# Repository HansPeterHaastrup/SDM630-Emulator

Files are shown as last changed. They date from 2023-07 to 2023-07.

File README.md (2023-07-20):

# SDM630-Emulator
Emulate the basic functionality of the Eastron SDM630 using Home-Assistant, MQTT and Arduino

## About
I have a large house. I wanted to install solar cells on my roof. I already have the Eastron SDM630 metering my connection and I am happy to get that information in to my Home-assistant installation.
The Deye inverters support the Eastron meter but by connecting the meter directly would not only require me to pull an absurdly long cable through my house but I would also loose the monitoring ability in Home-assistant.
This project emulates the SDM630 so the home-assistant data can be retained while allowing the inverters to get fast updates on the current power consumption.

## Prerequisites
1. A Home-assistant installation.
2. A MQTT Broker (Mosquitto is usually installed along Home-assistant)
3. ESPHome (installable on Home-assistant)
4. and SDM630 meter (Duh)

## Hardware
The hardware required is the same on each end - An ESP8266 with RS-485 interface. I have opted to use a cheap interface found on ebay and a NodeMCU. I have made a little enclosure for it. Powering the sensor in each end is done by a small USB power supply. nothing fancy.

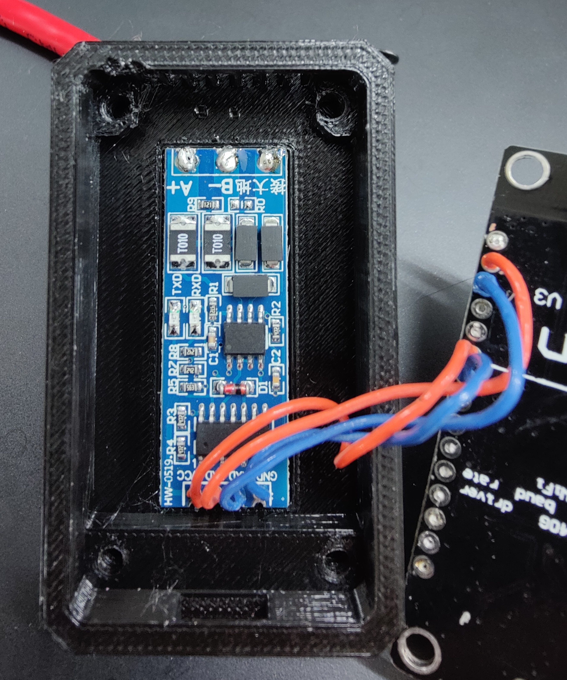
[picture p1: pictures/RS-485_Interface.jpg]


The enclosure have 3 small holes for screw terminals, from left to right the connections are GND,B,A.
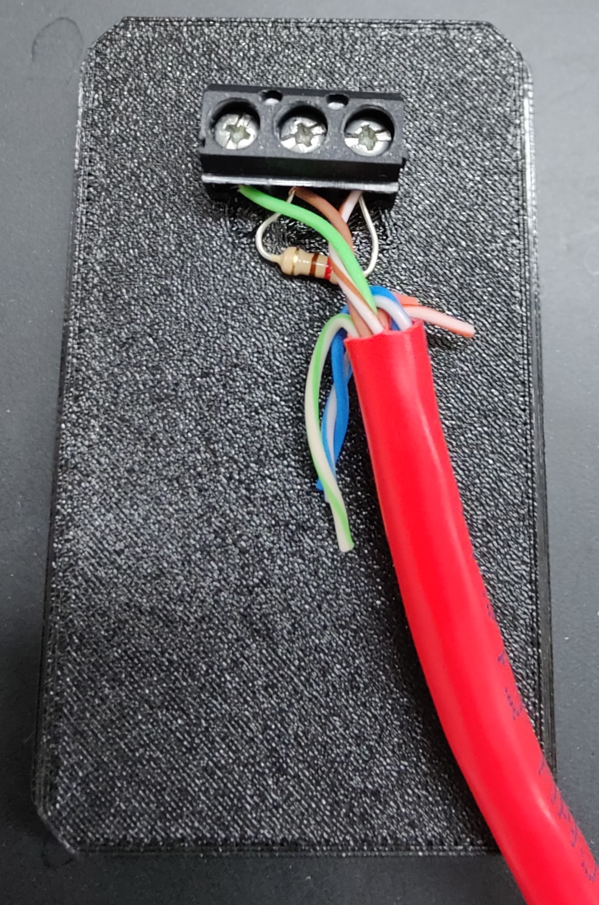
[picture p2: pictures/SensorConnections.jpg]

I have added the 120Ohm resistor but I'm not completely sure it's needed (nor the GND wire but hey, it works!)

## Firmware for metering node
For the sensor in the metering end I have used ESPHome. Create a standard sensor and add the following:
```
mqtt:
  broker: IP-TO-THE-BROKER (IP of Home-assistant)
  username: !secret mosquittouser
  password: !secret mosquittopassword

substitutions:
  phase_A: R
  phase_B: S
  phase_C: T

uart:
  rx_pin: 5
  tx_pin: 4
  baud_rate: 9600
  stop_bits: 1

sensor:
  - platform: sdm_meter
    phase_a:
      current:
        name: $phase_A Current
      voltage:
        name: $phase_A Voltage
      active_power:
        name: $phase_A Power
      power_factor:
        name: $phase_A Power Factor
      apparent_power:
        name: $phase_A Apparent Power
      reactive_power:
        name: $phase_A Reactive Power
      phase_angle:
        name: $phase_A Phase Angle
    phase_b:
      current:
        name: $phase_B Current
      voltage:
        name: $phase_B Voltage
      active_power:
        name: $phase_B Power
      power_factor:
        name: $phase_B Power Factor
      apparent_power:
        name: $phase_B Apparent Power
      reactive_power:
        name: $phase_B Reactive Power
      phase_angle:
        name: $phase_B Phase Angle
    phase_c:
      current:
        name: $phase_C Current
      voltage:
        name: $phase_C Voltage
      active_power:
        name: $phase_C Power
      power_factor:
        name: $phase_C Power Factor
      apparent_power:
        name: $phase_C Apparent Power
      reactive_power:
        name: $phase_C Reactive Power
      phase_angle:
        name: $phase_C Phase Angle

    frequency:
      name: "Frequency"
    total_power:
      name: "Total Power"
    import_active_energy:
      name: "Import Active Energy"
    export_active_energy:
      name: "Export Active Energy"
    import_reactive_energy:
      name: "Import Reactive Energy"
    export_reactive_energy:
      name: "Export Reactive Energy"
    
    update_interval: 2s
```
This will make all the data available in Home-assistant.
A few highlights:
1. The MQTT section. by adding this section you will get ALL values sent to the MQTT broker as well. it IS possible to script just the few registers needed for the emulator to work but this is by far the easiest solution.
2. The UART section. On the nodeMCU pin 4 and 5 works fine. YMMW
3. Last line. Update interval. The inverter queries the meter every second. While it is possible to get the sensor to answer faster by requesting less information I rather like the datapoints here. So far the 2 seconds seem to work just great.
4. The names of the phases. I have chosen the R,S,T naming convention (Root-Stem-Top) but you cah choose whichever you want. You just have to update the names in the receiving end as well if you do.

## Firmware for inverter node
See the Arduino sketch supplied in the repo.
You will need the MQTT libary 'PubSubClient' by Nick O'Leary installed to compile this project.
Adjust the section in 'User definitions' accordingly.

## Getting it all to work
There are many steps to get this thing to work. I recommend first installing the metering node and getting data flowing into the Home-Assistant. This should be fairly straight forward if you have used ESPHome before.
When the node ide running you will have to look at the MQTT part. For this I have found the program [MQTT Explorer](http://mqtt-explorer.com/) extremely helpful. by using this and connecting to your MQTT Broker you can see the data available on different topics. I am by no means an expert on MQTT but I could easily see what was going on.
Next, it's time to set up the receiving node. Please bear in mind that this project as of now is made for Deye inverters. Your inverter might ask for different registers that I haven't relayed through this method. YMMW.
Using the debug prints in the arduino sketch can prove extremely helpful. Start with making the sensor see the updates on your sensor topic in the MQTT broker. When that is running properly you can add the RS-485 communication with the inverter.
Good luck :)

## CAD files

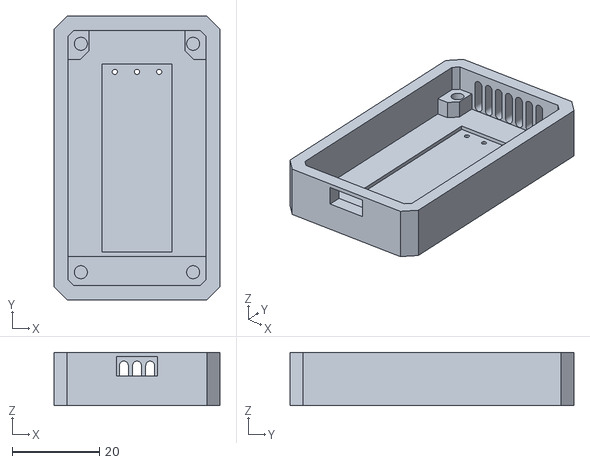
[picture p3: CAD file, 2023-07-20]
Mechanical/RS-485Node_Front.stl
38.0 x 65.0 x 12.2

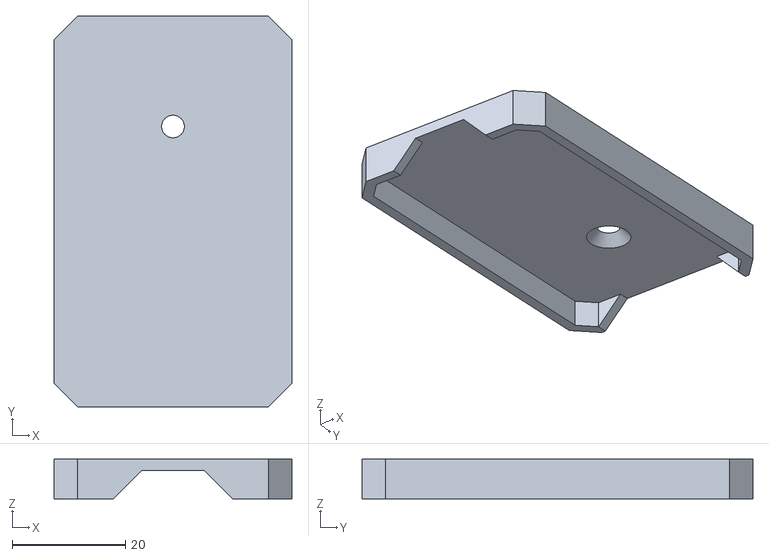
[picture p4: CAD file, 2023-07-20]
Mechanical/RS-485Node_Back.stl
42.0 x 69.0 x 7.00

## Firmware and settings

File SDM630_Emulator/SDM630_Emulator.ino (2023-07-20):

//#include <WiFi.h> //if using ESP32
#include <ESP8266WiFi.h>  //is using ESP8266
#include <PubSubClient.h>
#include <Wire.h>
#include <SoftwareSerial.h>

SoftwareSerial SoftSerial(4, 5);
WiFiClient espClient;
PubSubClient client(espClient);

/******************USER DEFINITIONS***************************/
#define DEBUG 0                                       //Set to 1 if you want debug prints :)
#define DEBUG_RS485 1

const char* ssid = "SSID";                    //WiFi SSID/Password combination
const char* password = "PASSWORD";

// Add your MQTT Broker IP address:
const char* mqtt_server = "IP-OF-YOUR-BROKER";
const char* mtqq_user = "MQTT-USERNAME";
const char* mtqq_password = "MQTT-PASSWORD";
const char* mtqq_device = "SDM630Emulator";
const char* mtqq_topic = "powersensor/sensor/#";        //the sensor to subscribe to (the # enables all sub-topics)
/******************END USER DEFINITIONS***********************/

uint8_t registers[160]; //this will hold the data up to and inclusive parameter 40 as per SDM630 manual. (4-bytes per parameter)

uint16_t calc_crc(uint8_t* data, uint8_t length) {
  uint16_t crc = 0xFFFF;
  for (int pos = 0; pos < length; pos++) {
    crc ^= data[pos];
    for (int i = 0; i < 8; i++) {
      if ((crc & 1) != 0) {
        crc >>= 1;
        crc ^= 0xA001;
      } else {
        crc >>= 1;
      }
    }
  }
  return crc;
}

void handleInverter() 
{
  if (SoftSerial.available()>7)                                      //handle incomming requests
  {
    static uint8_t recbuffer[8]={0x00,0x00,0x00,0x00,0x00,0x00,0x00,0x00};

    unsigned char firstByte = SoftSerial.read();

    if(firstByte==0x01)
    {
      recbuffer[0]=0x01;
      for(int i=1;i<8;i++)
      {
        recbuffer[i] = SoftSerial.read();
      }
   
      if(DEBUG_RS485)
      {
        Serial.print(millis());
        Serial.print(" ");
        for (int i = 0; i < 8; i++) 
        {
          Serial.print(" ");
          if(recbuffer[i]<16)
            Serial.print("0");
          Serial.print(recbuffer[i], HEX);
        }
        Serial.println();
      }
  
      if (calc_crc(recbuffer, 8) != 0)                              //if CRC doesn't match, return
      {
        Serial.println("malformed packet");
        return;
      }
    }
    else
    {
      static uint8_t recbuffer2[13]={0x00,0x00,0x00,0x00,0x00,0x00,0x00,0x00,0x00,0x00,0x00,0x00,0x00};
      recbuffer2[0]=firstByte;
      while(SoftSerial.available()<12) {}
      for(int i=1;i<13;i++)
      {
        recbuffer2[i] = SoftSerial.read();
      }
   
      if(DEBUG_RS485)
      {
        Serial.print(millis());
        Serial.print("This weird one ");
        for (int i = 0; i < 13; i++) 
        {
          Serial.print(" ");
          if(recbuffer2[i]<16)
            Serial.print("0");
          Serial.print(recbuffer2[i], HEX);
        }
        Serial.println();
      }
      return;
    }
        
    uint8_t slaveadr = recbuffer[0];
    uint8_t functioncode = recbuffer[1];
    uint16_t address = (recbuffer[2] << 8) | recbuffer[3];
    uint16_t numRegisters = (recbuffer[4] << 8) | recbuffer[5];
 
    if(DEBUG_RS485)
    {
      Serial.print(" process register read ");
      Serial.print(slaveadr);
      Serial.print(" ");
      Serial.print(functioncode);
      Serial.print(" ");
      Serial.print(address);
      Serial.print(" ");
      Serial.println(numRegisters);
    }
    
    //build up the array for returning values
    uint8_t response[(numRegisters*2)+3+2]; //make space for the header and CRC - the registers are 16-bit values so they take up double space!
    for(int i=0;i<sizeof(response);i++)
      response[i]=0;

    //build up the header
    response[0]=0x01;                                               //set slave address
    response[1]=0x04;                                               //response type
    response[2]=numRegisters*2;                                       //remember the registers are 16-bit values

    //fill in the response from the local registers
    uint16_t responseP=0;
    for(int i=(address*2);i<((address*2)+(numRegisters*2));i++)                       //start at the address requested (multiply by 2 to get 16-bit values)
    {
      response[responseP+3]=registers[i];                           //copy to the response array - dont overwrite the header!
      responseP++;
    }

    uint16_t crc = calc_crc(response, (sizeof(response)-2));          //calculate CRC (don't calculate on the empty CRC fields)
    
    response[sizeof(response)-2] = crc & 0xFF;                      //insert CRC
    response[sizeof(response)-1] = (crc >> 8) & 0xFF;  
    
    if(DEBUG_RS485)
    {
      Serial.print("response");
      for (int i = 0; i < sizeof(response); i++) 
      {
        Serial.print(" ");
        if(response[i]<16)
          Serial.print("0");
        Serial.print(response[i], HEX);
      }
      Serial.println();
    }
    
    SoftSerial.write(response, sizeof(response));                   //Write the response!
    memset(recbuffer, 0, sizeof(recbuffer));                        //reset buffer for incoming message
  }
}

void setup() 
{
  Serial.begin(115200);
  setup_wifi();
  client.setServer(mqtt_server, 1883);
  client.setCallback(callback);
  SoftSerial.begin(9600, SWSERIAL_8N1);
}

void setup_wifi() 
{
  if(DEBUG)
  {
  Serial.println();
  Serial.print("Connecting to ");
  Serial.println(ssid);
  }

  WiFi.begin(ssid, password);               // We start by connecting to a WiFi network

  while (WiFi.status() != WL_CONNECTED)     //waiting to connect...
  {
    delay(500);
    Serial.print(".");
  }
  if(DEBUG)
  {
    Serial.println("");
    Serial.println("WiFi connected");
    Serial.println("IP address: ");
    Serial.println(WiFi.localIP());
  }
}

union converter                             //Some C magic for converting a float into a byte-array ;)
{
  float val;
  unsigned char b[4];
}x;

void insertIntoRegisters(uint8_t startAddress)  
{
  registers[startAddress]   = x.b[3]; //and do a endianness conversion at the same time
  registers[startAddress+1] = x.b[2];
  registers[startAddress+2] = x.b[1];
  registers[startAddress+3] = x.b[0];
}

void callback(char* topic, byte* message, unsigned int length) 
{
  String messageTemp;                  
  for (int i = 0; i < length; i++) 
    messageTemp += (char)message[i];
  x.val=messageTemp.toFloat();  //save in union

  if(DEBUG)
  { 
    Serial.print("Message arrived on topic: ");
    Serial.print(topic);
    Serial.print(". Message: ");
    Serial.println(messageTemp.toFloat());
  }
  
  String topicc(topic);         //create a string for searching
  //the magic sauce of mapping the values to the SDM630 registers - NOTE: The MQTT topics are defined in the transmitter!
  
  if(topicc.indexOf("r_voltage/") > 0) insertIntoRegisters(0);
  if(topicc.indexOf("s_voltage/") > 0) insertIntoRegisters(4);
  if(topicc.indexOf("t_voltage/") > 0) insertIntoRegisters(8);
  
  if(topicc.indexOf("r_current/") > 0) insertIntoRegisters(12);
  if(topicc.indexOf("s_current/") > 0) insertIntoRegisters(16);
  if(topicc.indexOf("t_current/") > 0) insertIntoRegisters(20);

  if(topicc.indexOf("r_power/") > 0) insertIntoRegisters(24);
  if(topicc.indexOf("s_power/") > 0) insertIntoRegisters(28);
  if(topicc.indexOf("t_power/") > 0) insertIntoRegisters(32);

  if(topicc.indexOf("r_apparent_power/") > 0) insertIntoRegisters(36);
  if(topicc.indexOf("s_apparent_power/") > 0) insertIntoRegisters(40);
  if(topicc.indexOf("t_apparent_power/") > 0) insertIntoRegisters(44);

  if(topicc.indexOf("r_reactive_power/") > 0) insertIntoRegisters(48);
  if(topicc.indexOf("s_reactive_power/") > 0) insertIntoRegisters(52);
  if(topicc.indexOf("t_reactive_power/") > 0) insertIntoRegisters(56);

  if(topicc.indexOf("r_power_factor/") > 0) insertIntoRegisters(60);
  if(topicc.indexOf("s_power_factor/") > 0) insertIntoRegisters(64);
  if(topicc.indexOf("t_power_factor/") > 0) insertIntoRegisters(68);

  if(topicc.indexOf("r_phase_angle/") > 0) insertIntoRegisters(72);
  if(topicc.indexOf("s_phase_angle/") > 0) insertIntoRegisters(76);
  if(topicc.indexOf("t_phase_angle/") > 0) insertIntoRegisters(80);

  if(topicc.indexOf("total_power/") > 0)             insertIntoRegisters(104);
  if(topicc.indexOf("frequency/") > 0)               insertIntoRegisters(140);

  if(topicc.indexOf("import_active_energy/") > 0)    insertIntoRegisters(144);
  if(topicc.indexOf("export_active_energy/") > 0)    insertIntoRegisters(148);
  if(topicc.indexOf("import_reactive_energy/") > 0)  insertIntoRegisters(152);
  if(topicc.indexOf("export_reactive_energy/") > 0)  insertIntoRegisters(156);
}

void loop() 
{
  if (!client.connected()) 
  {
    while (!client.connected())                                         // Loop until we're reconnected
    {
      Serial.print("Attempting MQTT connection...");
      if (client.connect(mtqq_device,mtqq_user,mtqq_password))          // Attempt to connect
      {
        Serial.println("connected");
        client.subscribe(mtqq_topic);                                   // Subscribe
      } 
      else 
      {
        Serial.print("failed, rc=");
        Serial.print(client.state());
        Serial.println(" try again in 5 seconds");     
        delay(5000);                                                    // Wait 5 seconds before retrying
      }
    }
  }
  client.loop();

  handleInverter();                                                     // handle communication with the inverter
}
